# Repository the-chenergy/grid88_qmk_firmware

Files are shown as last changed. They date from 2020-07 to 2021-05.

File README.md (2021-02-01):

# Asianboii's Custom Keyboard

*Finally got a big update from my cheap keyboard. This bad boy killed it!*

***
## Design Source Files

* Keycaps: https://github.com/asianboii-chen/grid88_qmk_firmware/tree/master/design_sources/keycaps
* Cases: https://github.com/asianboii-chen/grid88_qmk_firmware/tree/master/design_sources/cases
  * 3D-Preview the Cases: https://a360.co/3dU7cbU
* Firmware: this repository :D

***
## Gallery

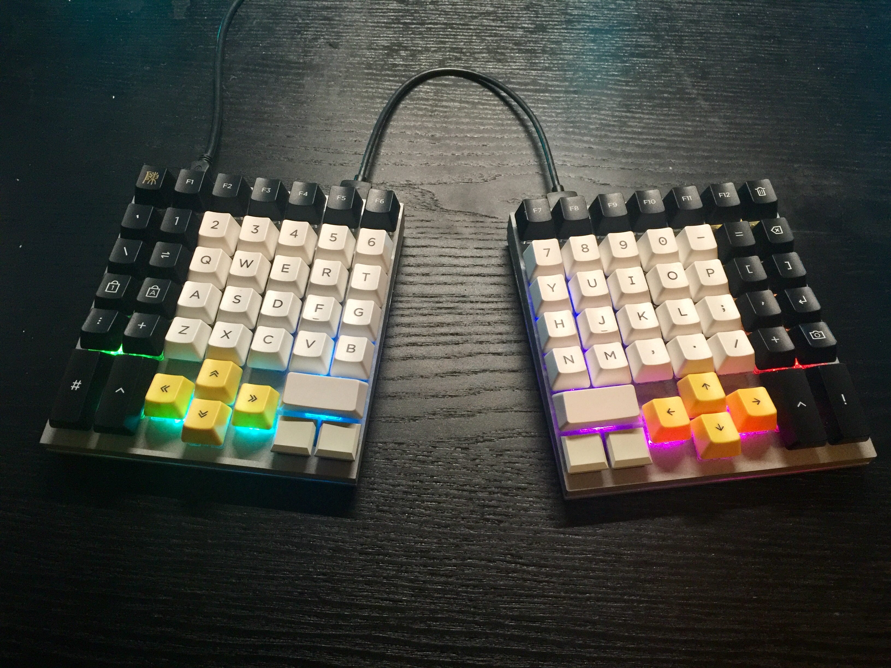
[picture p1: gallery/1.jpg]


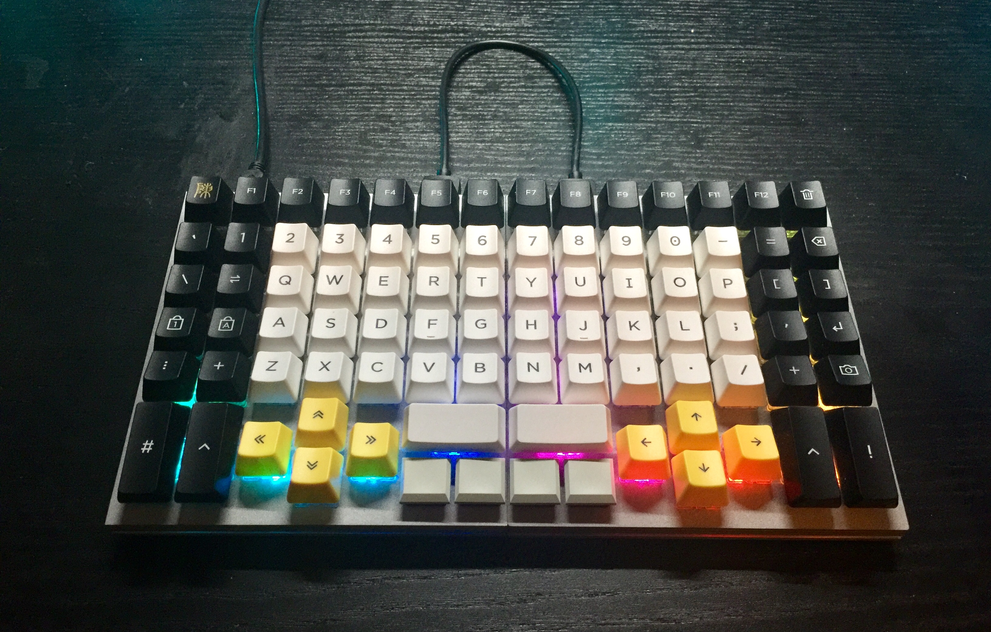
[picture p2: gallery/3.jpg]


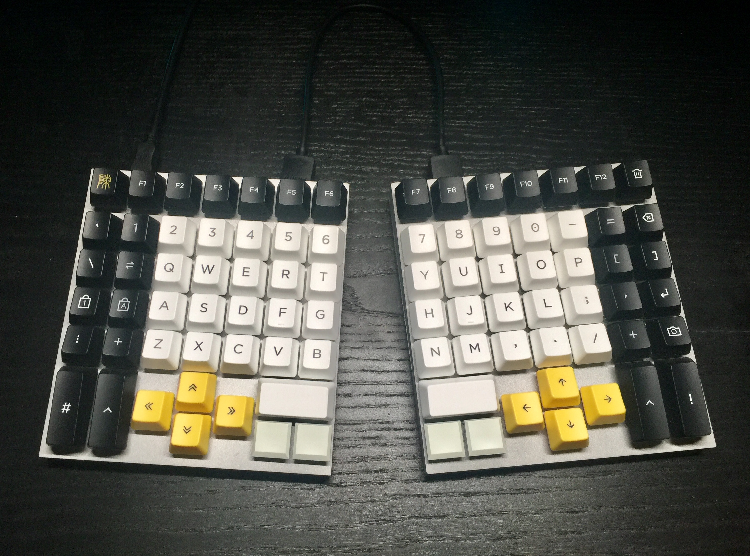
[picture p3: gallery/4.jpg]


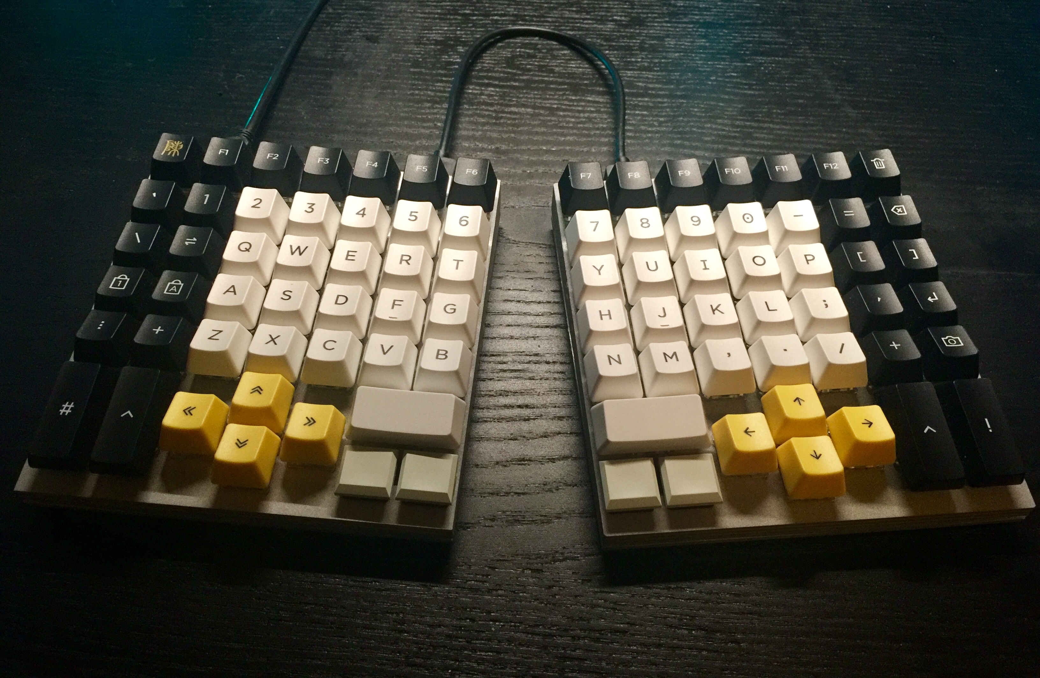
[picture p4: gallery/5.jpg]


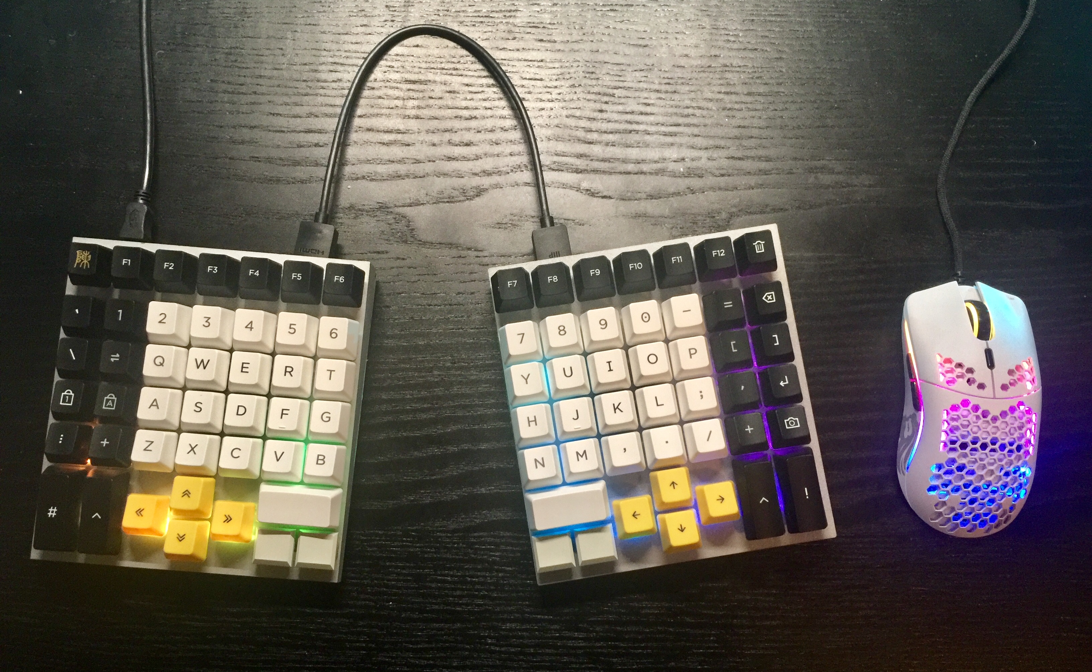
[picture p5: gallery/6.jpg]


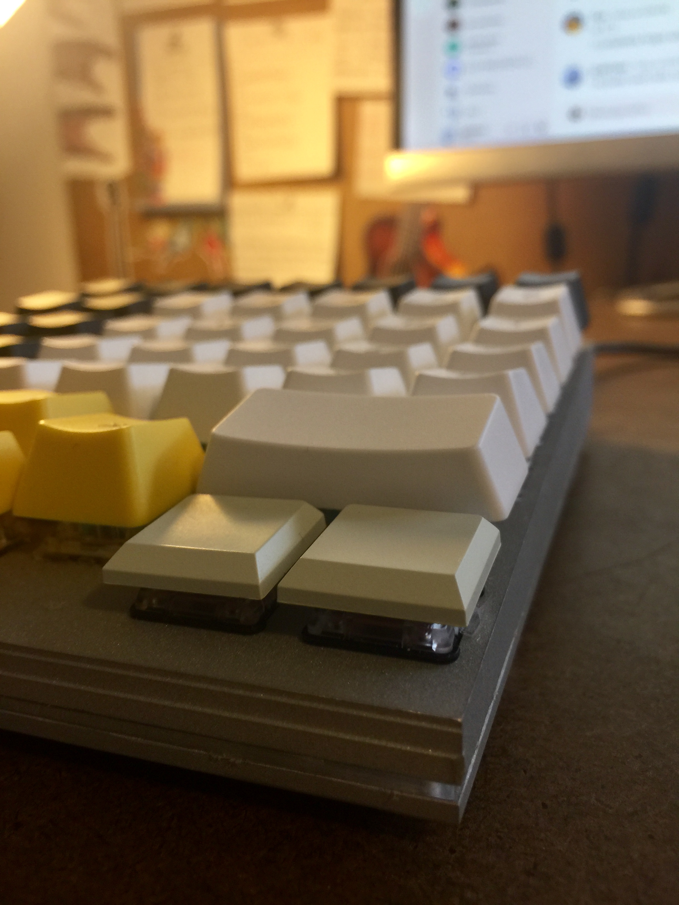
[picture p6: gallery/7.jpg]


***
## In Progress

These are the components I prepared and used for building this keyboard:

* 1 pair of aluminum+acrylic cases by ACP Precision
* 84 Zeal Zilent switches 
  * Spring-swapped with Sprit MX Supreme 50G (35g actuation, 50g bottom out)
* 4 Kailh Choc Orange switches
  * Spring-swapped with Sprit Choc 35G (35g actuation, 45g bottom out)
* All switches lubed with Tribosys 3204 on housings and springs, borrowed from Kevin
* 1 custom ISO keycap set on Maxkeyboard (OEM profile)
* 4 Kailh Choc keycaps
* 88 1N4148 diodes
* 1 WS2812B RGB LED strip (30 LEDs/meter)
* Enough electric wires/ribbon cables (28 AWG gauge but it is a pain to solder; <=24 AWG would be ideal)
* Electric tape
* 1 Teensy 2.0 micro-controller (24 pins)
* 1 six-foot micro-B to USB-A cable
* 2 HDMI breakout boards (19 pins each)
* 1 one-foot HDMI 4K cable (19 pins)
* Solder station and solder borrowed from Kevin (*see* [*Credits*](https://github.com/asianboii-chen/grid88_qmk_firmware#Credits))

The building process took 6 days (24+ hours) as this is my first keyboard-build as well as my first big, constructive, and non-programming project in general. For the most part, I followed [Matt3o's tutorial](https://matt3o.com/book) (thank you Matteo) for both wiring and firmware writing.

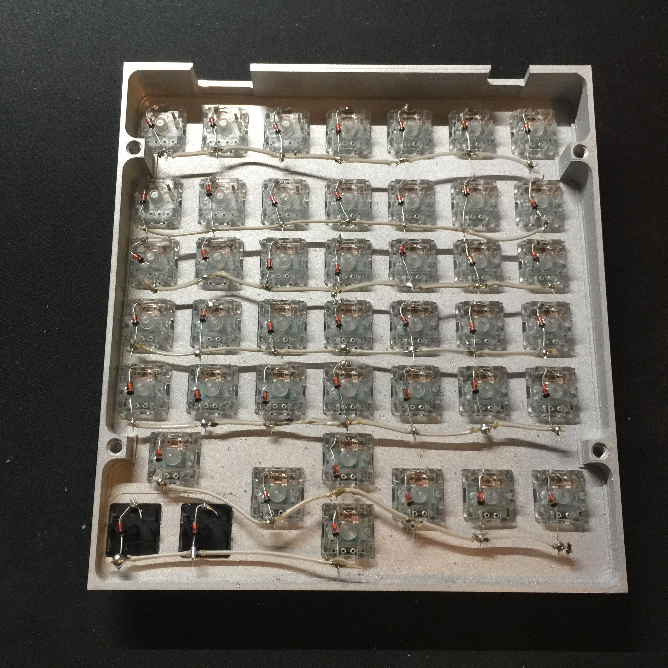
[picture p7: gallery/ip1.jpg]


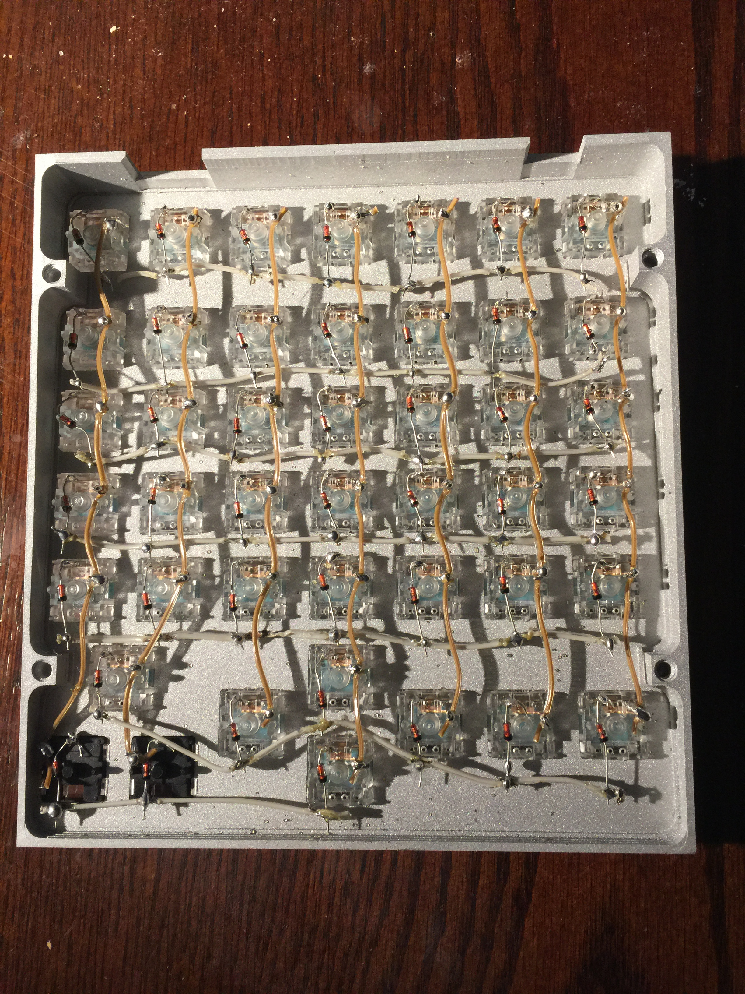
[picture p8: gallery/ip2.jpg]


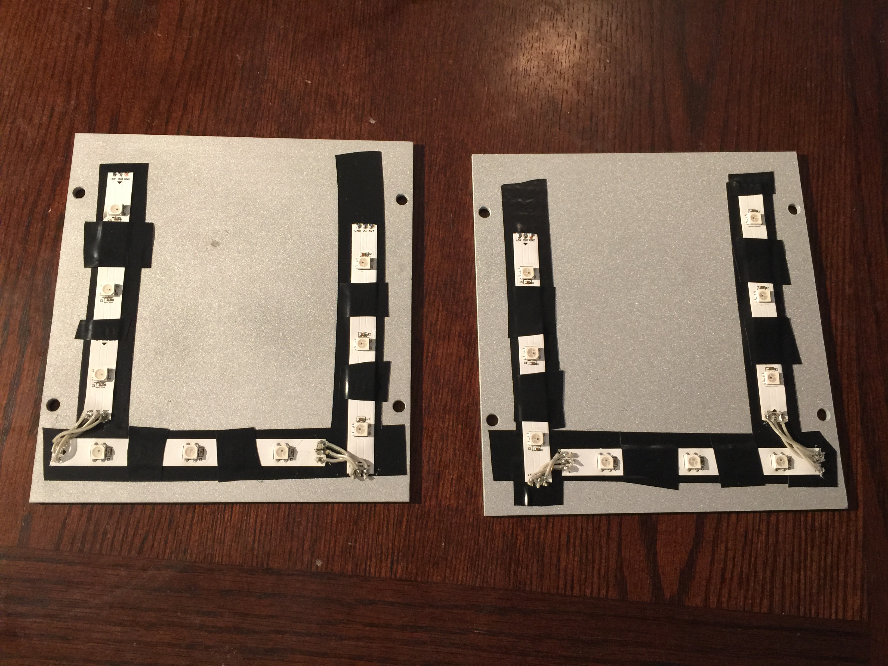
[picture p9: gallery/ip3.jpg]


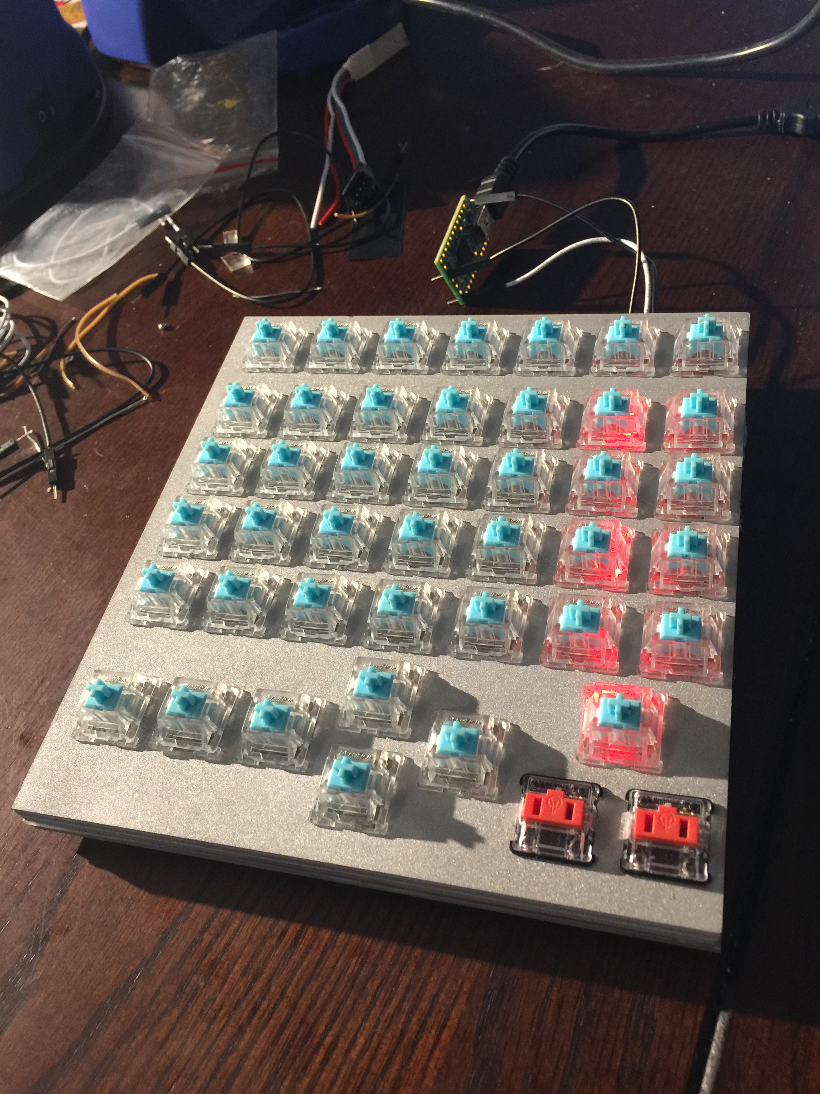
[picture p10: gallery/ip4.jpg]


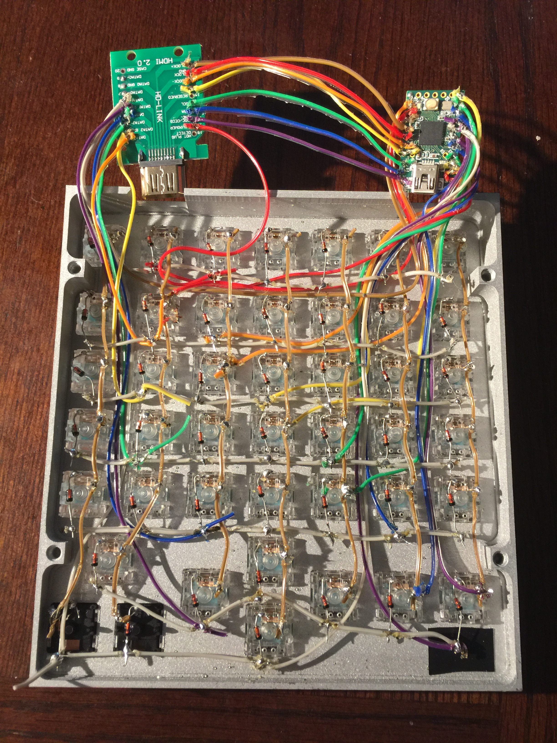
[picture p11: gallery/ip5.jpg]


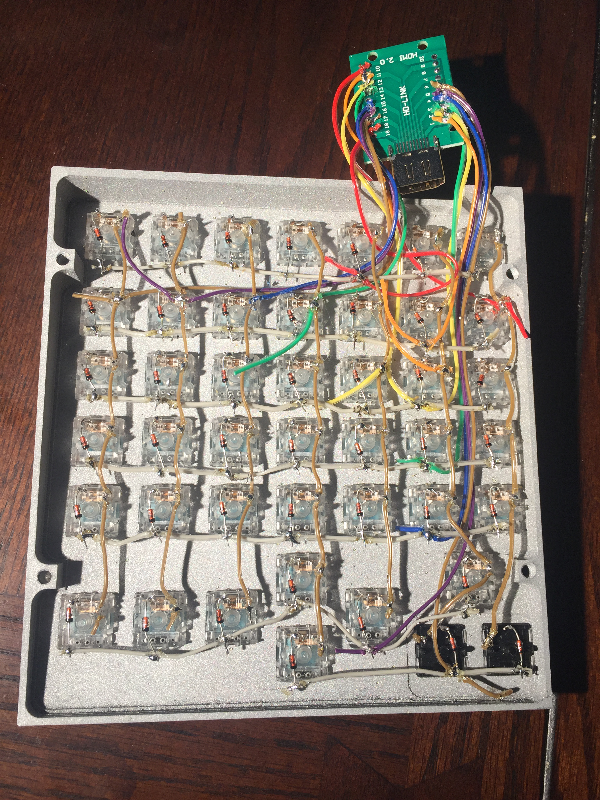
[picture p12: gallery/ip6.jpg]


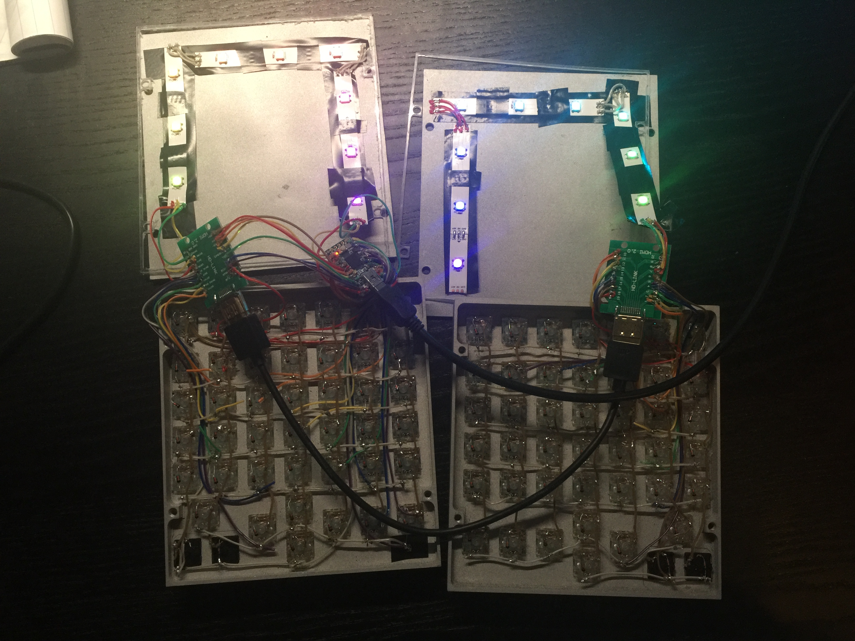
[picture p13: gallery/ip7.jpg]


Now just as I'm writing this up I realized I should've taken more photos from the building process :/

***
## About the Design

I designed the layout of this keyboard to better fit the principles of the [Asianboii's UI](https://github.com/asianboii-chen/AsianboiisUI/blob/master/4.1/README.md) (the keyboard layout I'm using), namely to increase and balance the usages of the strong fingers and to save the pinkies from doing laborious work. This design aims to make the palm-keys and thumb-keys more reachable and comfortable which will serve the purposes of a custom layout better. I chose to go with an ortholinear layout for (1) a pleasing "gridded" look, (2) an easier time finding keys on the number-row and function-row since the keys are all lined up, and (3) a hypothetically smoother transition between it and the traditional layout compared to a [columnar-staggered layout](https://deskthority.net/wiki/Staggering#Columnar_layout).

This is the layout on how I think a normal person would use it:



It's perfectly serviceable and has most of the advantages that those ergonomic keyboards out there have. It not only brings the most-used pinkie-keys (Tab, Shift, Enter, and Backspace) under the thumbs, but it also makes the Ctrl keys more naturally pressed by the palms. Its split feature also allows one to bring their mouse closer to the keyboard. However, as advertised, I don't use the Qwerty layout anymore, so here's the layout in my mind: *(if you think it's confusing, just know that I'm weird)*



Check out [this page](https://github.com/asianboii-chen/AsianboiisUI/blob/master/README.md) for more information on why I invented my own funny layout.

I'll check back and add what I feel about this keyboard after a while. Can't wait to see how this keyboard will contribute to my next semester.

***
## Credits

Huge shout out to Derrick from ACP Precision for helping me with the design and making the cases for this keyboard. I could not have dreamt of this project without him.
* Derrick on 100kGarages: https://100kgarages.com/profile.php?id=14510
* Derrick's email: acpprecisionllc@gmail.com
* Derrick's Discord username: ACP PRECISION LLC#3310

Big thank you to my homie Kevin for his help, awesome battle-station to give birth to this project, and equally avid passion toward keyboards. Definitely go bother him!
* Kevin on YouTube: https://www.youtube.com/user/KevinSong1995
* Kevin on GitHub: https://github.com/Bettsongy
* Kevin's Discord username: Kev#1097

Gratitude to everyone who has contributed to this wonderful keyboard community, especially to those like Matt3o who had written very helpful tutorials that help beginners like me.

Qianlang

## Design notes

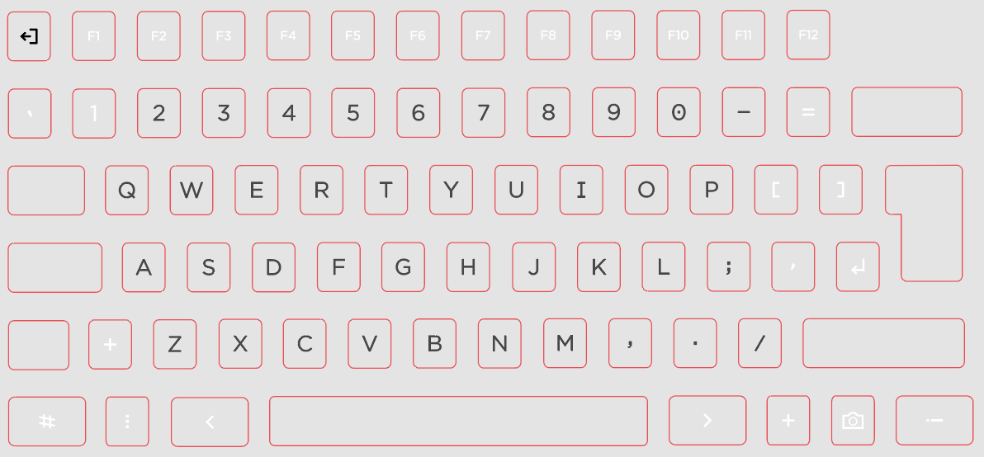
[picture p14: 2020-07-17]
design_sources/keycaps/full_set_preview.png

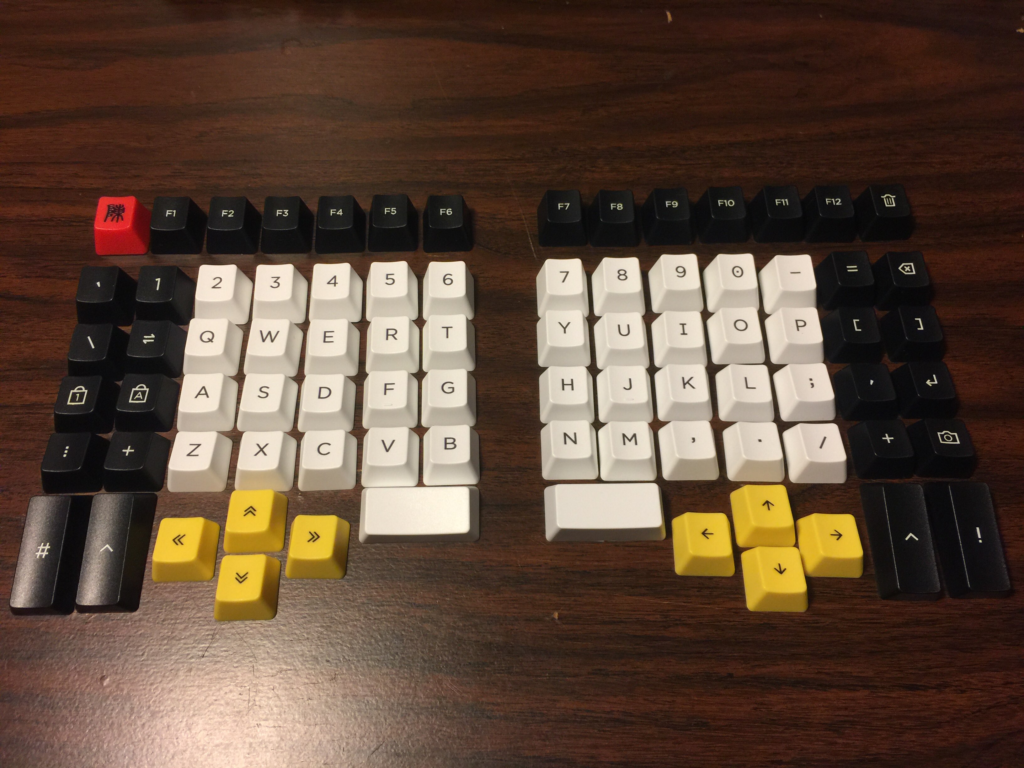
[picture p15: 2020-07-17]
design_sources/keycaps/full_set_product.jpg

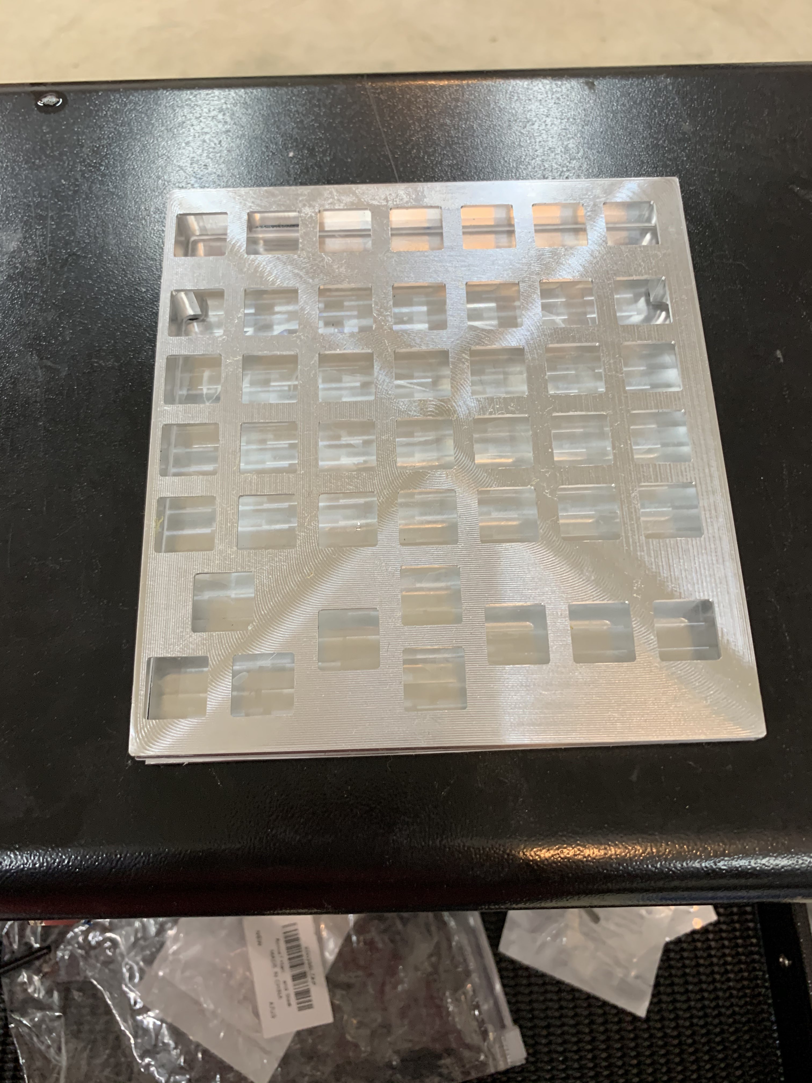
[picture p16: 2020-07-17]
design_sources/cases/sample_product.jpg

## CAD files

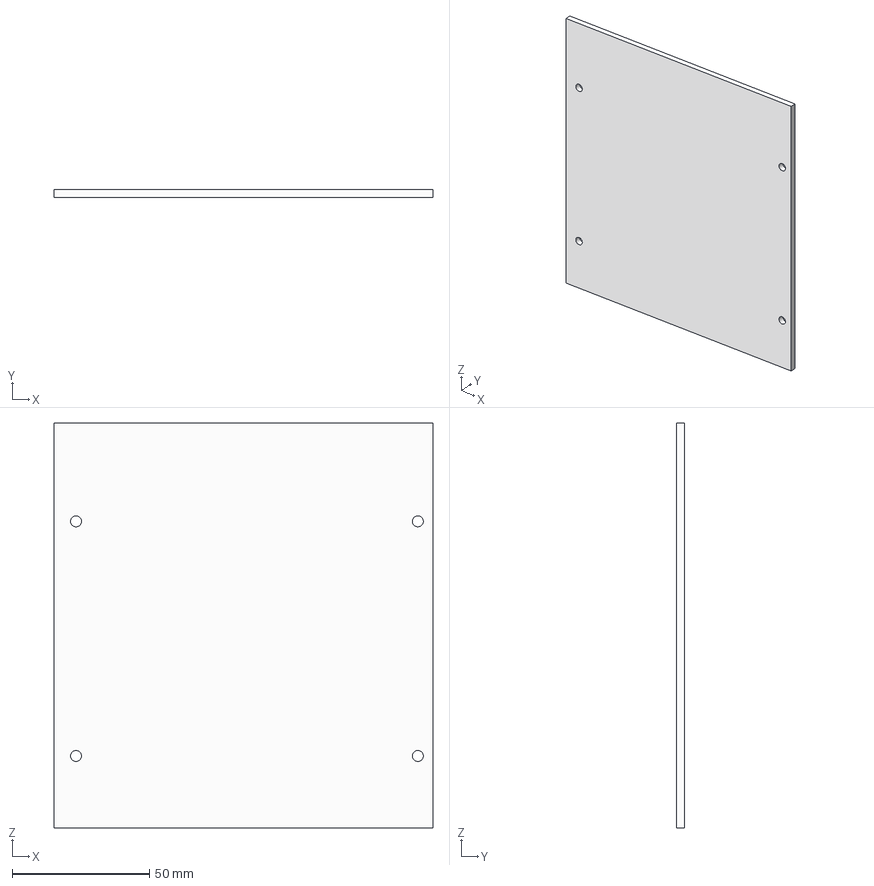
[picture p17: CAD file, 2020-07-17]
design_sources/cases/bottom.step
138.1 x 3.00 x 147.6 mm

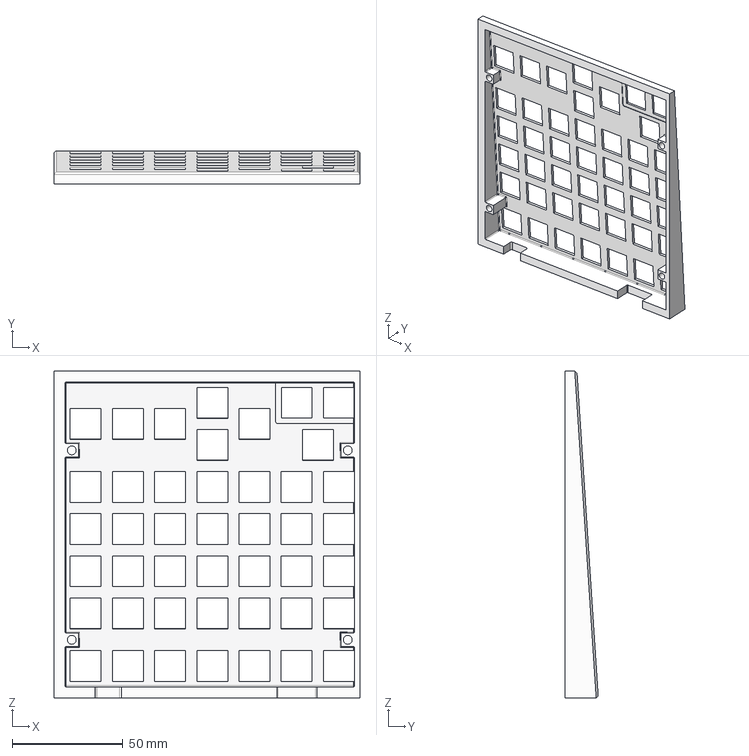
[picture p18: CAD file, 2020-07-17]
design_sources/cases/left_top.step
138.1 x 15.1 x 147.6 mm

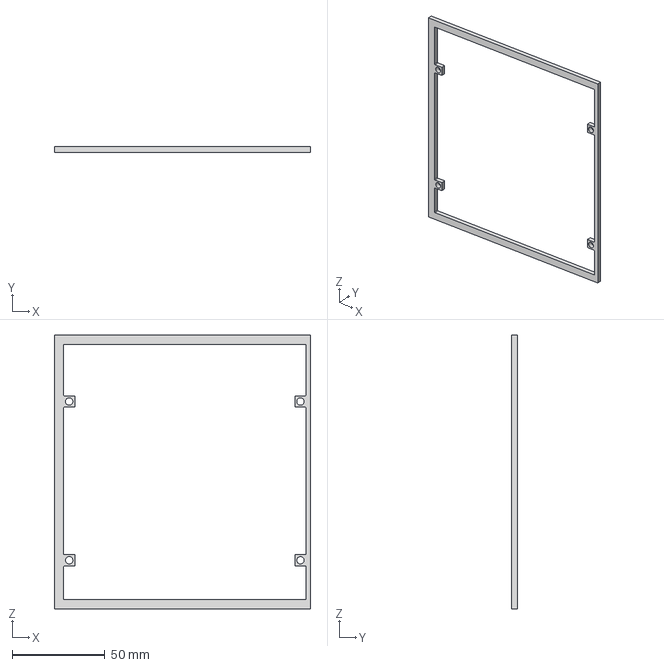
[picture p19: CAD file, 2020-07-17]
design_sources/cases/middle.step
138.1 x 3.00 x 147.6 mm

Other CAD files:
design_sources/cases/right_top.step
design_sources/cases/source.f3d

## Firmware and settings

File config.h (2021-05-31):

/**
 * defines pin configurations for grid88, a custom handwired keyboard.
 *
 * qianlang chen
 * m 05/31/21
 */

#ifndef CONFIG_H
#define CONFIG_H

#include "config_common.h"

/* keyboard descriptions */

#define VENDOR_ID 0xFEED
#define PRODUCT_ID 0x0001
#define DEVICE_VER 0x0001
#define MANUFACTURER qianlang chen
#define PRODUCT grid88
#define DESCRIPTION a custom handwired split keyboard.

/* matrix configs */

#define MATRIX_ROWS 7
#define MATRIX_COLS 14
#define MATRIX_ROW_PINS \
  { B0, B1, B2, B3, B7, D0, D1 }
#define MATRIX_COL_PINS \
  { D2, D3, C6, C7, D7, B4, B5, B6, F7, F6, F5, F4, F1, F0 }
#define UNUSED_PINS

#define DIODE_DIRECTION COL2ROW

/* led strip configs */

#define RGB_DI_PIN D6

#define RGBLED_NUM 18

#define RGBLIGHT_HUE_STEP 16
#define RGBLIGHT_SAT_STEP 32
#define RGBLIGHT_VAL_STEP 21
#define RGBLIGHT_LIMIT_VAL 84
#define RGBLIGHT_ANIMATIONS

#define RGBLIGHT_LAYERS
#define RGBLIGHT_LAYER_BLINK
#define RGBLIGHT_SLEEP

/* additional keyboard features */

#define FORCE_NKRO

#define DEBOUNCE 24

#define PREVENT_STUCK_MODIFIERS

#define LOCKING_SUPPORT_ENABLE
#define LOCKING_RESYNC_ENABLE

#define TAPPING_TERM 174
#define PERMISSIVE_HOLD
#define TAPPING_FORCE_HOLD

#endif /* CONFIG_H */

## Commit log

2020-05-11 v0.2\n- removed deprecated function usages.\n- created no-led version for testing before putting in the led strip.
2020-07-17 uploading raw design files
    [bottom.step, left_top.step, middle.step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]
2020-12-08 Basic suppport of the Asianboii's UI - Fixed numpad problem of outputting unicode junk for punctuation characters. + AsUI's function layer isn't too good at cursor moving and selecting text + AsUI do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
    [config.h]
2020-12-08 v0.3: Improved basic/limited support for the AsUI - Fixed some key-assignment problems. - Fixed the problem where the AsUI couldn't be properly toggled with the one-shot Fn key (by separating on/off).
    [config.h]
2021-05-31 v0.4: Updated the layout and fixed the tap-hold repeat issue
    [config.h]
